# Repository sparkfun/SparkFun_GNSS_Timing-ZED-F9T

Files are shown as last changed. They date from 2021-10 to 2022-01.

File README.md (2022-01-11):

SparkFun GNSS Timing Breakout - ZED-F9T (Qwiic)
========================================

SparkFun GNSS Timing Breakout - ZED-F9T (Qwiic) (https://www.sparkfun.com/products/18774)

[*SparkFun GNSS Timing Breakout - ZED-F9T (Qwiic) (GPS-18774)*](https://www.sparkfun.com/products/18774)

The SparkFun GNSS Timing Breakout - ZED-F9T (Qwiic) offers a unique entry into SparkFun&apos;s GNSS catalog featuring the ZED-F9T GNSS receiver from u-blox. The ZED-F9T provides up to 5 nanosecond timing accuracy under clear skies with no external GNSS correction. The ZED-F9T supports L1/L2 bands and operates on all major constellations concurrently so it is able to maintain its timing precision even if the module loses connection with on or more of the visible constellations.

The breakout includes a USB-C connector for primary power and communication, two Qwiic connectors for communicating over I<sup>2</sup>C using the SparkFun [Qwiic system](https://www.sparkfun.com/qwiic), three SMA connectors for the antenna and timing pulse signals as well as a host of PTH pins allowing direct interaction with most of the ZED-F9T's pinout. The board also includes an on-board rechargeable battery that provides power to the RTC on the ZED-F9T. This reduces the time-to-first fix from a cold start (~24s) to a hot start (~2s). 

Repository Contents
-------------------

* **/Documents** - Datasheet, Appnotes.
* **/Hardware** - Eagle design files (.brd, .sch)

Documentation
-------------

* **[SparkFun u-blox GNSS Arduino Library](https://github.com/sparkfun/SparkFun_u-blox_GNSS_Arduino_Library)** - A comprehensive library for all SparkFun u-blox products.
* **[Hookup Guide](https://learn.sparkfun.com/tutorials/gnss-timing-breakout---zed-f9t-qwiic-hookup-guide)** - A basic Hookup Guide to get started with the SparkFun GNSS Timing Breakout - ZED-F9T (Qwiic).

Product Versions
----------------
* [GPS-18774](https://www.sparkfun.com/products/18774) - Initial release

Version History
---------------
* v1.0 - Initial Release 

License Information
-------------------

This product is _**open source**_! 

Please review the LICENSE.md file for license information. 

If you have any questions or concerns on licensing, please contact technical support on our [SparkFun forums](https://forum.sparkfun.com/viewforum.php?f=152).

Distributed as-is; no warranty is given.

- Your friends at SparkFun.

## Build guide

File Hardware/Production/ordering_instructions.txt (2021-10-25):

panel size, 199x101mm
PCB thickness, 1.6mm
number of layers, 4
controlled impedance, JLC7628
soldermask color, Red
silkscreen color, White
oz copper, 1oz
finish, ENIG
stencils, none
pcs per panel, 8
min trace width, 0.1778mm / 0.0070in
min drill size, 0.3048mm / 0.0120in
filename to layer stackup 1/2/3/4: GTL, GL2, GL3, GBL

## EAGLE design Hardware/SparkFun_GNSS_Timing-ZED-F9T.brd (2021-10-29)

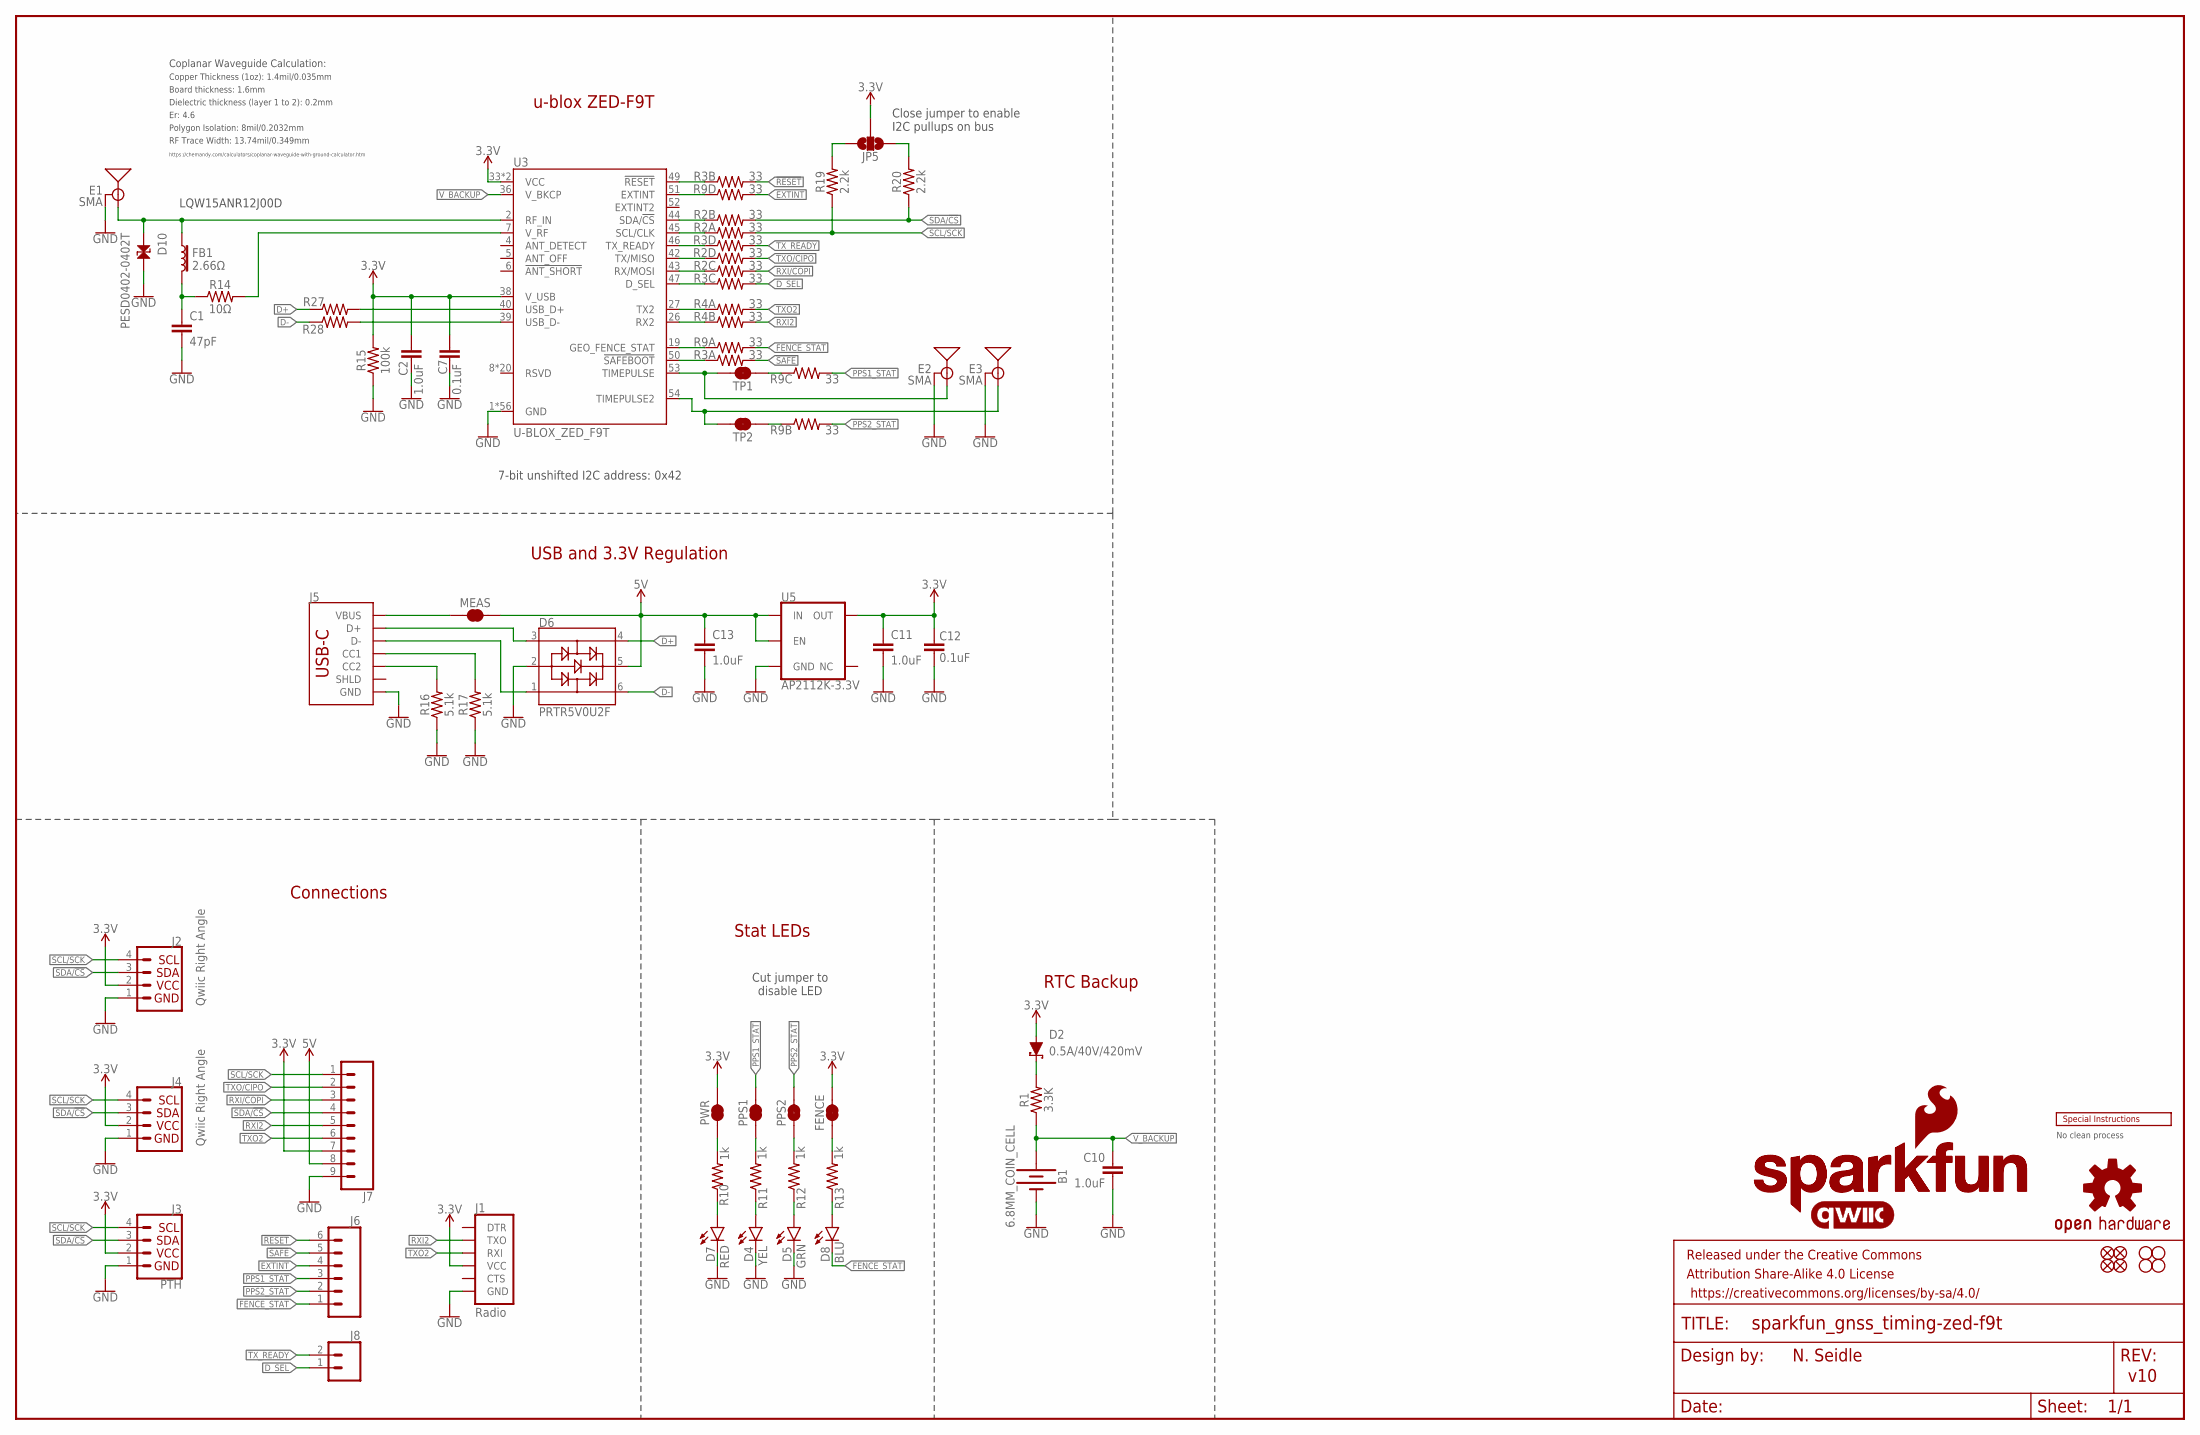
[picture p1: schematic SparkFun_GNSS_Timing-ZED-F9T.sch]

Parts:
B1: 6.8MM_COIN_CELL; ML414H_IV01E
C1: 47pF; 0402-TIGHT
C2, C10, C11, C13: 1.0uF; 0402-TIGHT
C7, C12: 0.1uF; 0402-TIGHT
D2: 0.5A/40V/420mV; SOD-323
D4: YEL; LED-0603
D5: GRN; LED-0603
D6: PRTR5V0U2F; SOT886
D7: RED; LED-0603
D8: BLU; LED-0603
D10: PESD0402-0402T; 0402-TIGHT
E1, E2, E3: SMA; SMA-EDGE
FB1: 2.66Ω; 0402-TIGHT
FENCE: JUMPER-SMT_2_NC_TRACE_SILK; SMT-JUMPER_2_NC_TRACE_SILK
FRAME2: FRAME-LEDGER; CREATIVE_COMMONS
H1, H2, H3, H4: STAND-OFF
J1: Radio; 1X06_NO_SILK
J2, J4: Qwiic Right Angle; JST04_1MM_RA
J3: PTH; 1X04_NO_SILK
J5: USB Female Type C Connector; USB-C-16P_4LAYER-PADS
J6: CONN_06NO_SILK_FEMALE_PTH; 1X06_NO_SILK
J7: CONN_09NO_SILK; 1X09_NO_SILK
J8: CONN_021X02_NO_SILK; 1X02_NO_SILK
JP5: JUMPER-SMT_3_NO_SILK; SMT-JUMPER_3_NO_SILK
JP21, JP61, JP71, JP81: FIDUCIALUFIDUCIAL; FIDUCIAL-MICRO
LOGO1: OSHW-LOGOMINI; OSHW-LOGO-MINI
LOGO2: SFE_LOGO_NAME_FLAME.1_INCH; SFE_LOGO_NAME_FLAME_.1
LOGO4: QWIIC_LOGO_4MM; QWIIC_4MM
LOGO5: SFE_LOGO_NAME.1_INCH; SFE_LOGO_NAME_.1
MEAS: JUMPER-COMBO_2_NC_TRACE; COMBO-JUMPER_2_NC_TRACE
PPS1, PPS2: JUMPER-SMT_2_NC_TRACE_SILK; SMT-JUMPER_2_NC_TRACE_SILK
PWR: JUMPER-SMT_2_NC_TRACE_SILK; SMT-JUMPER_2_NC_TRACE_SILK
R1: 3.3K; 0402-TIGHT
R2, R3, R4, R9: 33; 1206_RA
R10, R11, R12, R13: 1k; 0402-TIGHT
R14: 10Ω; 0402-TIGHT
R15: 100k; 0402-TIGHT
R16, R17: 5.1k; 0402-TIGHT
R19, R20: 2.2k; 0402-TIGHT
R27, R28: 27OHM; 0402-TIGHT
TP1, TP2: JUMPER-SMT_2_NC_TRACE_SILK; SMT-JUMPER_2_NC_TRACE_SILK
U3: U-BLOX_ZED_F9T; ZED-F9X
U5: AP2112K-3.3V; SOT23-5
U$2: SPECIAL_INSTRUCTIONS-ORDERING; ORDERING_INSTRUCTIONS

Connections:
3.3V: C2.1, C7.2, C11.1, C12.2, D2.A, FENCE.2, J1.4 (VCC), J2.2, J3.2 (VCC), J4.2, J7.7, JP5.2, PWR.2, R15.2, U3.33 (VCC), U3.34 (VCC), U3.38 (V_USB), U5.5 (OUT)
5V: C13.1, D6.5, J7.8, MEAS.2, MEAS.4 (2), U5.1 (IN), U5.3 (EN)
!RESET!: J6.6, R3.P7 (2)
!RESET!_LV: R3.P2 (1), U3.49 (!RESET!)
!SAFE!: J6.5, R3.P8 (2)
!SAFE!_LV: R3.P1 (1), U3.50 (!SAFEBOOT!)
ANT_VCC: C1.1, FB1.2, R14.1
CC1: J5.A5 (CC1), R17.2
CC2: J5.B5 (CC2), R16.2
D+: D6.4, R27.1
D-: D6.6, R28.1
DSEL_LV: R3.P3 (1), U3.47 (D_SEL)
D_SEL: J8.1, R3.P6 (2)
EXTINT: J6.4, R9.P5 (2)
EXTINT_LV: R9.P4 (1), U3.51 (EXTINT)
FENCE_LV: R9.P1 (1), U3.19 (GEO_FENCE_STAT)
FENCE_STAT: D8.C, J6.1, R9.P8 (2)
GND: B1.-, C1.2, C2.2, C7.1, C10.2, C11.2, C12.1, C13.2, D4.C, D5.C, D6.2, D7.C, D10.2, E1.GND@0 (GND), E1.GND@1 (GND), E1.GND@2 (GND), E1.GND@3 (GND), E2.GND@0 (GND), E2.GND@1 (GND), E2.GND@2 (GND), E2.GND@3 (GND), E3.GND@0 (GND), E3.GND@1 (GND), E3.GND@2 (GND), E3.GND@3 (GND), J1.6 (GND), J2.1, J3.1 (GND), J4.1, J5.GND, J5.GND2 (GND), J7.9, R15.1, R16.1, R17.1, U3.1 (GND), U3.3 (GND), U3.12 (GND), U3.14 (GND), U3.32 (GND), U3.37 (GND), U3.41 (GND), U3.48 (GND), U3.G1 (GND), U3.G2 (GND), U3.G3 (GND), U3.G4 (GND), U3.G5 (GND), U3.G6 (GND), U3.G7 (GND), U3.G8 (GND), U3.G9 (GND), U3.G10 (GND), U3.G11 (GND), U3.G12 (GND), U3.G13 (GND), U3.G14 (GND), U3.G15 (GND), U3.G16 (GND), U3.G17 (GND), U3.G18 (GND), U3.G19 (GND), U3.G20 (GND), U3.G21 (GND), U3.G22 (GND), U3.G23 (GND), U3.G24 (GND), U3.G25 (GND), U3.G26 (GND), U3.G27 (GND), U3.G28 (GND), U3.G29 (GND), U3.G30 (GND), U3.G31 (GND), U3.G32 (GND), U3.G33 (GND), U3.G34 (GND), U3.G35 (GND), U3.G36 (GND), U3.G37 (GND), U3.G38 (GND), U3.G39 (GND), U3.G40 (GND), U3.G41 (GND), U3.G42 (GND), U3.G43 (GND), U3.G44 (GND), U3.G45 (GND), U3.G46 (GND), U3.G47 (GND), U3.G48 (GND), U5.2 (GND)
GPS_ANT1: D10.1, E1.SIG (SIGNAL), FB1.1, U3.2 (RF_IN)
unnamed: D4.A, R11.1
unnamed: PPS1.1, R11.2
unnamed: J5.VBUS1 (VBUS), J5.VBUS2 (VBUS), MEAS.1, MEAS.3 (1)
unnamed: R9.P3 (1), TP1.1
unnamed: D2.C, R1.2
unnamed: R9.P2 (1), TP2.1
unnamed: R27.2, U3.40 (USB_D+)
unnamed: R28.2, U3.39 (USB_D-)
unnamed: R14.2, U3.7 (V_RF)
unnamed: D7.A, R10.1
unnamed: D5.A, R12.1
unnamed: PPS2.1, R12.2
unnamed: D8.A, R13.1
unnamed: FENCE.1, R13.2
unnamed: PWR.1, R10.2
unnamed: JP5.1, R20.2
unnamed: JP5.3, R19.2
PPS1_STAT: J6.3, PPS1.2, R9.P6 (2)
PPS2_STAT: J6.2, PPS2.2, R9.P7 (2)
RX1_LV: R2.P3 (1), U3.43 (RX/MOSI)
RX2_LV: R4.P2 (1), U3.26 (RX2)
RXI2: J1.3 (TXO), J7.5, R4.P7 (2)
RXI/COPI: J7.3, R2.P6 (2)
SCL/SCK: J2.4, J3.4 (SCL), J4.4, J7.1, R2.P8 (2), R19.1
SCL_LV: R2.P1 (1), U3.45 (SCL/CLK)
SDA/!CS: J2.3, J3.3 (SDA), J4.3, J7.4, R2.P7 (2), R20.1
SDA_LV: R2.P2 (1), U3.44 (SDA/!CS!)
TP1_LV: E2.SIG (SIGNAL), TP1.2, U3.53 (TIMEPULSE)
TP2_LV: E3.SIG (SIGNAL), TP2.2, U3.54 (TIMEPULSE2)
TX1_LV: R2.P4 (1), U3.42 (TX/MISO)
TX2_LV: R4.P1 (1), U3.27 (TX2)
TXO2: J1.2 (RXI), J7.6, R4.P8 (2)
TXO/CIPO: J7.2, R2.P5 (2)
TX_READY: J8.2, R3.P5 (2)
TX_READY_LV: R3.P4 (1), U3.46 (TX_READY)
UNP_D+: D6.3, J5.A6 (D+), J5.B6 (D+)
UNP_D-: D6.1, J5.A7 (D-), J5.B7 (D-)
V_BACKUP: B1.+, C10.1, R1.1, U3.36 (V_BKCP)

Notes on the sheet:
v10
7-bit unshifted I2C address: 0x42
u-blox ZED-F9T
LQW15ANR12J00D
Board thickness: 1.6mm
Er: 4.6
Copper Thickness (1oz): 1.4mil/0.035mm
RF Trace Width: 13.74mil/0.349mm
Polygon Isolation: 8mil/0.2032mm
No clean process
Dielectric thickness (layer 1 to 2): 0.2mm
https://chemandy.com/calculators/coplanar-waveguide-with-ground-calculator.htm
Coplanar Waveguide Calculation:
USB and 3.3V Regulation
N. Seidle
Cut jumper to disable LED
RTC Backup
Close jumper to enable I2C pullups on bus
Stat LEDs
Connections

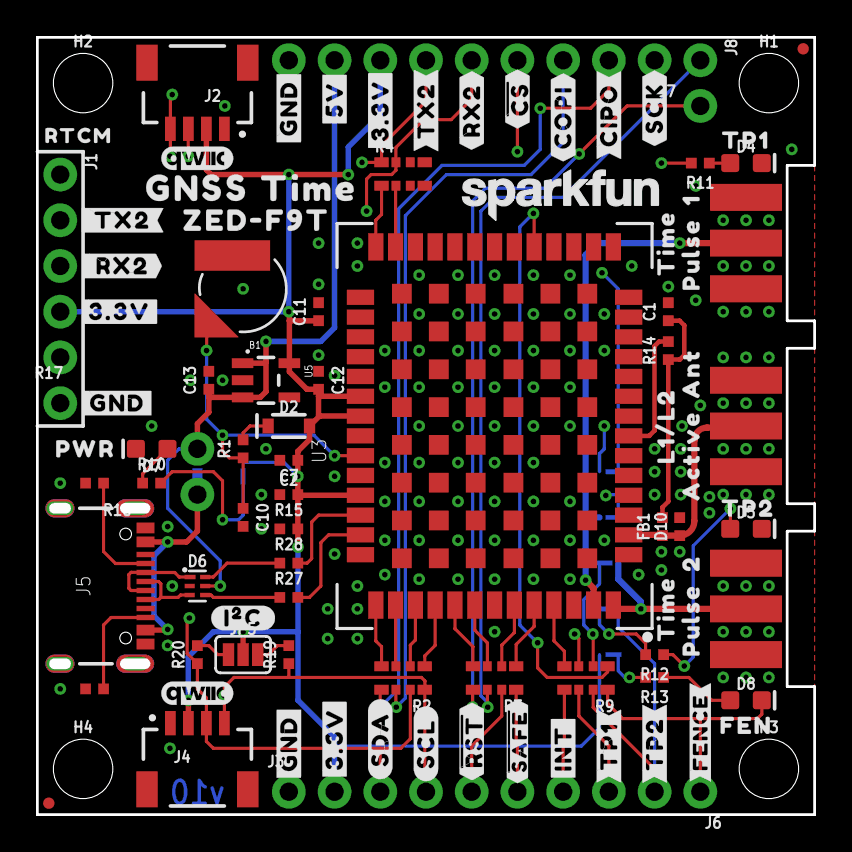
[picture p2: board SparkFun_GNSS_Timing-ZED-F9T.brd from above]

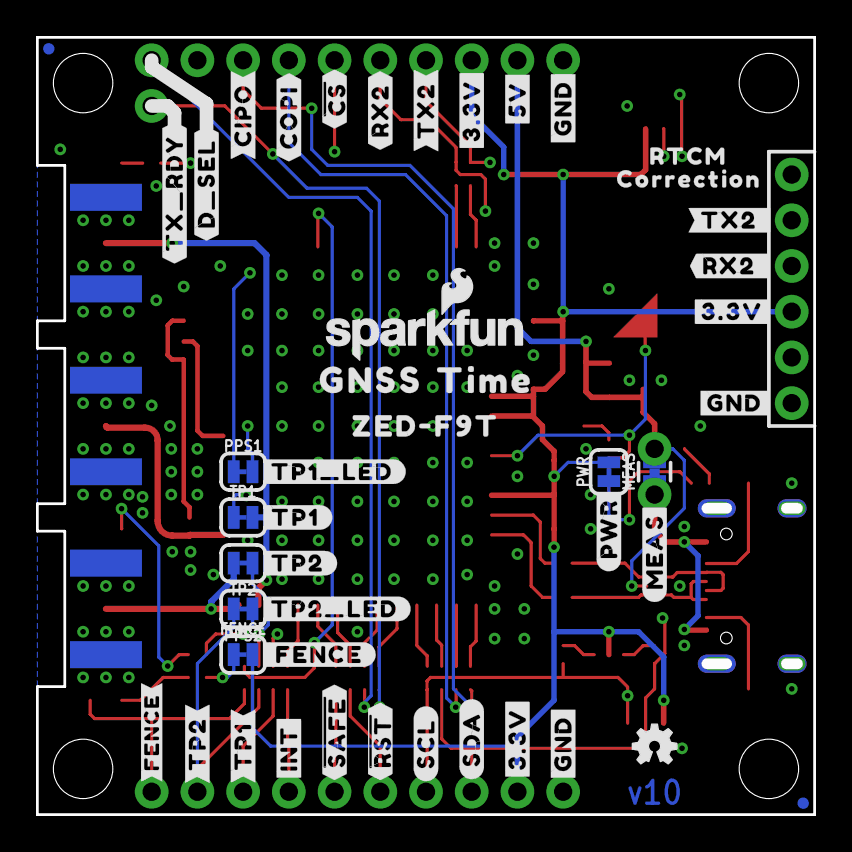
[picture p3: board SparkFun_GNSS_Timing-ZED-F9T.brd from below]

Board: 4 copper layers, 43.2 x 43.2 mm, 146 parts (47 on the bottom side), 57 nets.

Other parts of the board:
LOGO3: QWIIC_LOGO_4MM; QWIIC_4MM
U$1, U$29, U$35, U$36, U$59, U$60: #3#3V#0
U$3, U$28: #5V#1
U$4, U$27, U$38, U$39, U$61, U$62: #GND#2
U$5, U$8: ##CS##4
U$6: L1#L20
U$7, U$21: TIME0
U$9, U$10: #CIPO#6
U$11, U$12: #COPI#5
U$13: ACTIVE1
U$14, U$16: #RX2#1
U$15, U$37: ##RST##0
U$17, U$53: #SCL#3
U$18, U$22: #SDA#2
U$19, U$25: PULSE1
U$20: 12
U$23, U$24: #TX2#0
U$26: 20
U$30: #SCK#5
U$31: ANT1
U$32: #_TX2#0
U$33: #D_SEL#1
U$34, U$77: ZED#F9T0
U$40, U$70: GNSS0
U$41: ##SAFE##1
U$42, U$43: #INT#2
U$44, U$65: #FENCE#0
U$45: #TP2_LED#0
U$46, U$47: #TP1#3
U$48, U$49: #TP2#4
U$50: #TP2#0
U$51: #_FENCE#0
U$52: #TP1#0
U$54: #TP1_LED#0
U$55: #_RX2#0
U$56: PWR0
U$57: #PWR#0
U$58: #RX2_#0
U$63: TP10
U$64: TP21
U$66: #TX2_#0
U$67: #TX_RDY#0
U$68: #MEAS#0
U$69: #I�C#0
U$71, U$74: TIME1
U$72: ##SAFE##0
U$73: RTCM0
U$75: CORRECTION1
U$76: RTCM_0
U$78: FEN0

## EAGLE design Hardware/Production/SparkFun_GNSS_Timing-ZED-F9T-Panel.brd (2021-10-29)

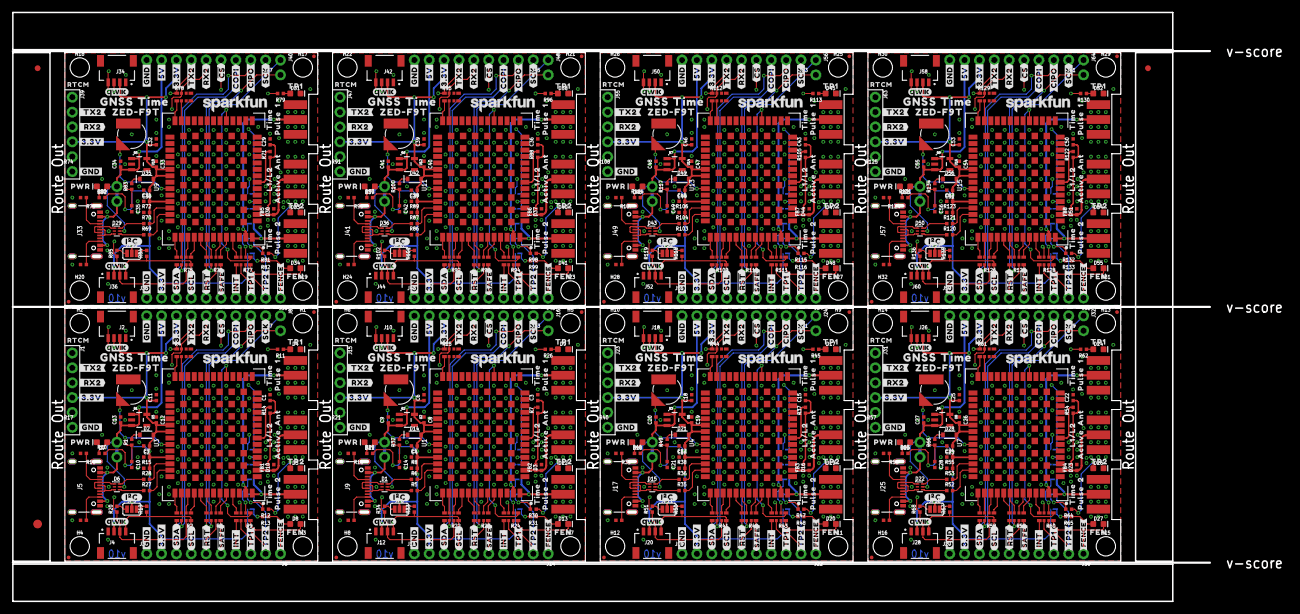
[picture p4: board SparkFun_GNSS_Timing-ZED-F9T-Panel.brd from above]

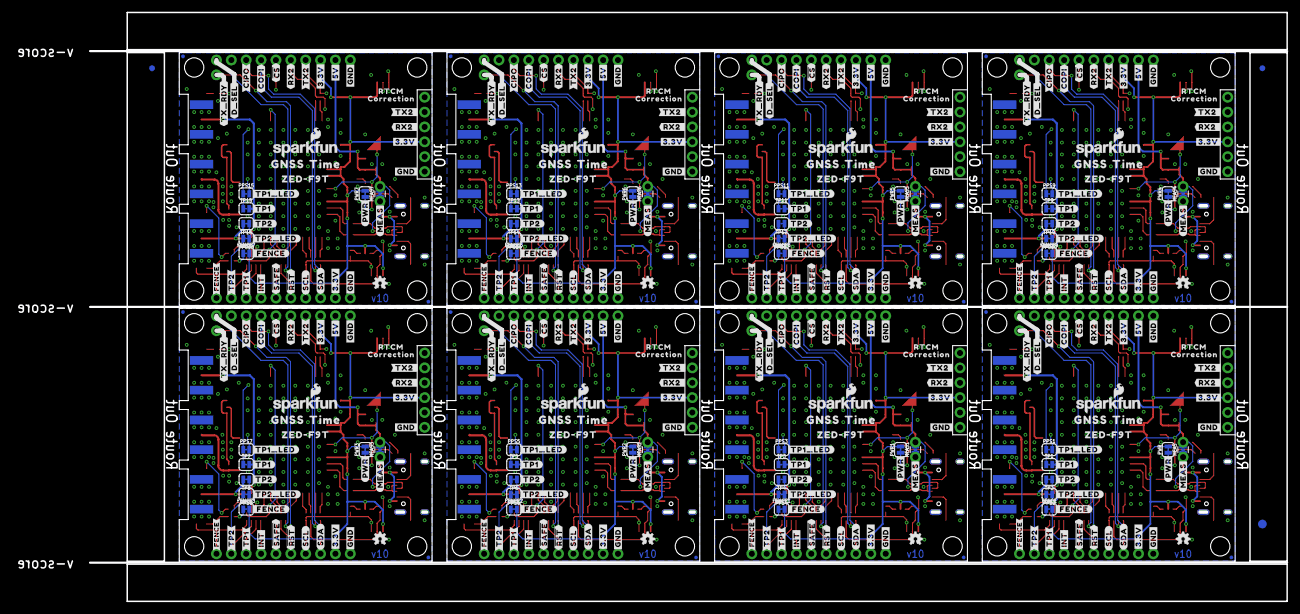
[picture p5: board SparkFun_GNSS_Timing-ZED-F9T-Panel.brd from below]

Board: 4 copper layers, 204.5 x 100.6 mm, 1158 parts (379 on the bottom side), 456 nets.

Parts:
B1, B2, B3, B4, B5, B6, B7, B8: 6.8MM_COIN_CELL; ML414H_IV01E
C1, C3, C15, C22, C29, C36, C43, C50: 47pF; 0402-TIGHT
C2, C4, C6, C9, C10, C11, C13, C14, C16, C18, C20, C21, C23, C25, C27, C28, C30, C32, C34, C35, C37, C39, C41, C42, C44, C46, C48, C49, C51, C53, C55, C56: 1.0uF; 0402-TIGHT
C5, C7, C8, C12, C17, C19, C24, C26, C31, C33, C38, C40, C45, C47, C52, C54: 0.1uF; 0402-TIGHT
D1, D6, D15, D22, D29, D36, D43, D50: PRTR5V0U2F; SOT886
D2, D14, D21, D28, D35, D42, D49, D56: 0.5A/40V/420mV; SOD-323
D3, D10, D16, D23, D30, D37, D44, D51: PESD0402-0402T; 0402-TIGHT
D4, D9, D17, D24, D31, D38, D45, D52: YEL; LED-0603
D5, D12, D19, D26, D33, D40, D47, D54: GRN; LED-0603
D7, D11, D18, D25, D32, D39, D46, D53: RED; LED-0603
D8, D13, D20, D27, D34, D41, D48, D55: BLU; LED-0603
E1, E2, E3, E4, E5, E6, E7, E8, E9, E10, E11, E12, E13, E14, E15, E16, E17, E18, E19, E20, E21, E22, E23, E24: SMA; SMA-EDGE
E$1, E$2, E$3, E$4: FIDUCIAL-1X2
E$5, E$6: FIDUCIAL-1.5X3
FB1, FB2, FB3, FB4, FB5, FB6, FB7, FB8: 2.66Ω; 0402-TIGHT
FENCE, FENCE1, FENCE2, FENCE3, FENCE4, FENCE5, FENCE6, FENCE7: JUMPER-SMT_2_NC_TRACE_SILK; SMT-JUMPER_2_NC_TRACE_SILK
H1, H2, H3, H4, H5, H6, H7, H8, H9, H10, H11, H12, H13, H14, H15, H16, H17, H18, H19, H20, H21, H22, H23, H24, H25, H26, H27, H28, H29, H30, H31, H32: STAND-OFF
J1, J15, J23, J31, J39, J47, J55, J63: Radio; 1X06_NO_SILK
J2, J4, J10, J12, J18, J20, J26, J28, J34, J36, J42, J44, J50, J52, J58, J60: Qwiic Right Angle; JST04_1MM_RA
J3, J11, J19, J27, J35, J43, J51, J59: PTH; 1X04_NO_SILK
J5, J9, J17, J25, J33, J41, J49, J57: USB Female Type C Connector; USB-C-16P_4LAYER-PADS
J6, J14, J22, J30, J38, J46, J54, J62: 1X06_NO_SILK
J7, J13, J21, J29, J37, J45, J53, J61: 1X09_NO_SILK
J8, J16, J24, J32, J40, J48, J56, J64: 1X02_NO_SILK
JP1, JP2, JP3, JP4, JP7, JP8, JP9, JP10, JP12, JP13, JP14, JP15, JP17, JP18, JP19, JP20, JP21, JP23, JP24, JP25, JP26, JP28, JP29, JP30, JP31, JP33, JP34, JP35, JP36, JP61, JP71, JP81: FIDUCIALUFIDUCIAL; FIDUCIAL-MICRO
JP5, JP6, JP11, JP16, JP22, JP27, JP32, JP37: JUMPER-SMT_3_NO_SILK; SMT-JUMPER_3_NO_SILK
LOGO1, LOGO6, LOGO11, LOGO16, LOGO21, LOGO26, LOGO31, LOGO36: OSHW-LOGOMINI; OSHW-LOGO-MINI
LOGO2, LOGO7, LOGO12, LOGO17, LOGO22, LOGO27, LOGO32, LOGO37: SFE_LOGO_NAME_FLAME.1_INCH; SFE_LOGO_NAME_FLAME_.1
LOGO3, LOGO4, LOGO8, LOGO10, LOGO13, LOGO15, LOGO18, LOGO20, LOGO23, LOGO25, LOGO28, LOGO30, LOGO33, LOGO35, LOGO38, LOGO40: QWIIC_LOGO_4MM; QWIIC_4MM
LOGO5, LOGO9, LOGO14, LOGO19, LOGO24, LOGO29, LOGO34, LOGO39: SFE_LOGO_NAME.1_INCH; SFE_LOGO_NAME_.1
MEAS, MEAS1, MEAS2, MEAS3, MEAS4, MEAS5, MEAS6, MEAS7: JUMPER-COMBO_2_NC_TRACE; COMBO-JUMPER_2_NC_TRACE
PPS1, PPS2, PPS3, PPS4, PPS5, PPS6, PPS7, PPS8, PPS9, PPS10, PPS11, PPS12, PPS13, PPS14, PPS15, PPS16: JUMPER-SMT_2_NC_TRACE_SILK; SMT-JUMPER_2_NC_TRACE_SILK
PWR, PWR1, PWR2, PWR3, PWR4, PWR5, PWR6, PWR7: JUMPER-SMT_2_NC_TRACE_SILK; SMT-JUMPER_2_NC_TRACE_SILK
R1, R32, R49, R66, R83, R100, R117, R134: 3.3K; 0402-TIGHT
R2, R3, R4, R9, R22, R23, R24, R25, R41, R42, R43, R44, R58, R59, R60, R61, R75, R76, R77, R78, R92, R93, R94, R95, R109, R110, R111, R112, R126, R127, R128, R129: 33; 1206_RA
R5, R6, R27, R28, R35, R36, R52, R53, R69, R70, R86, R87, R103, R104, R120, R121: 27OHM; 0402-TIGHT
R7, R14, R37, R54, R71, R88, R105, R122: 10Ω; 0402-TIGHT
R8, R15, R38, R55, R72, R89, R106, R123: 100k; 0402-TIGHT
R10, R11, R12, R13, R26, R29, R30, R31, R45, R46, R47, R48, R62, R63, R64, R65, R79, R80, R81, R82, R96, R97, R98, R99, R113, R114, R115, R116, R130, R131, R132, R133: 1k; 0402-TIGHT
R16, R17, R18, R21, R39, R40, R56, R57, R73, R74, R90, R91, R107, R108, R124, R125: 5.1k; 0402-TIGHT
R19, R20, R33, R34, R50, R51, R67, R68, R84, R85, R101, R102, R118, R119, R135, R136: 2.2k; 0402-TIGHT
TP1, TP2, TP3, TP4, TP5, TP6, TP7, TP8, TP9, TP10, TP11, TP12, TP13, TP14, TP15, TP16: JUMPER-SMT_2_NC_TRACE_SILK; SMT-JUMPER_2_NC_TRACE_SILK
U1, U3, U4, U7, U9, U11, U13, U15: U-BLOX_ZED_F9T; ZED-F9X
U2, U5, U6, U8, U10, U12, U14, U16: AP2112K-3.3V; SOT23-5
U$1, U$29, U$35, U$36, U$59, U$60, U$88, U$106, U$108, U$109, U$127, U$128, U$165, U$183, U$185, U$186, U$204, U$205, U$242, U$260, U$262, U$263, U$281, U$282, U$319, U$337, U$339, U$340, U$358, U$359, U$396, U$414, U$416, U$417, U$435, U$436, U$473, U$491, U$493, U$494, U$512, U$513, U$550, U$568, U$570, U$571, U$589, U$590: #3#3V#0
U$2, U$6, U$155, U$232, U$309, U$386, U$463, U$540: L1#L20
U$3, U$28, U$89, U$105, U$166, U$182, U$243, U$259, U$320, U$336, U$397, U$413, U$474, U$490, U$551, U$567: #5V#1
U$4, U$27, U$38, U$39, U$61, U$62, U$90, U$104, U$110, U$111, U$129, U$130, U$167, U$181, U$187, U$188, U$206, U$207, U$244, U$258, U$264, U$265, U$283, U$284, U$321, U$335, U$341, U$342, U$360, U$361, U$398, U$412, U$418, U$419, U$437, U$438, U$475, U$489, U$495, U$496, U$514, U$515, U$552, U$566, U$572, U$573, U$591, U$592: #GND#2
U$5, U$8, U$91, U$92, U$168, U$169, U$245, U$246, U$322, U$323, U$399, U$400, U$476, U$477, U$553, U$554: ##CS##4
U$7, U$21, U$80, U$83, U$157, U$160, U$234, U$237, U$311, U$314, U$388, U$391, U$465, U$468, U$542, U$545: TIME0
U$9, U$10, U$93, U$94, U$170, U$171, U$247, U$248, U$324, U$325, U$401, U$402, U$478, U$479, U$555, U$556: #CIPO#6
U$11, U$12, U$95, U$96, U$172, U$173, U$249, U$250, U$326, U$327, U$403, U$404, U$480, U$481, U$557, U$558: #COPI#5
U$13, U$79, U$156, U$233, U$310, U$387, U$464, U$541: ACTIVE1
U$14, U$16, U$97, U$98, U$174, U$175, U$251, U$252, U$328, U$329, U$405, U$406, U$482, U$483, U$559, U$560: #RX2#1
U$15, U$37, U$112, U$113, U$189, U$190, U$266, U$267, U$343, U$344, U$420, U$421, U$497, U$498, U$574, U$575: ##RST##0
U$17, U$53, U$87, U$99, U$164, U$176, U$241, U$253, U$318, U$330, U$395, U$407, U$472, U$484, U$549, U$561: #SCL#3
U$18, U$22, U$100, U$101, U$177, U$178, U$254, U$255, U$331, U$332, U$408, U$409, U$485, U$486, U$562, U$563: #SDA#2
U$19, U$25, U$81, U$84, U$158, U$161, U$235, U$238, U$312, U$315, U$389, U$392, U$466, U$469, U$543, U$546: PULSE1
U$20, U$82, U$159, U$236, U$313, U$390, U$467, U$544: 12
U$23, U$24, U$102, U$103, U$179, U$180, U$256, U$257, U$333, U$334, U$410, U$411, U$487, U$488, U$564, U$565: #TX2#0
U$26, U$85, U$162, U$239, U$316, U$393, U$470, U$547: 20
U$30, U$107, U$184, U$261, U$338, U$415, U$492, U$569: #SCK#5
U$31, U$86, U$163, U$240, U$317, U$394, U$471, U$548: ANT1
U$32, U$136, U$213, U$290, U$367, U$444, U$521, U$598: #_TX2#0
U$33, U$135, U$212, U$289, U$366, U$443, U$520, U$597: #D_SEL#1
U$34, U$77, U$146, U$153, U$223, U$230, U$300, U$307, U$377, U$384, U$454, U$461, U$531, U$538, U$608, U$615: ZED#F9T0
U$40, U$70, U$144, U$151, U$221, U$228, U$298, U$305, U$375, U$382, U$452, U$459, U$529, U$536, U$606, U$613: GNSS0
U$41, U$114, U$191, U$268, U$345, U$422, U$499, U$576: ##SAFE##1
U$42, U$43, U$115, U$116, U$192, U$193, U$269, U$270, U$346, U$347, U$423, U$424, U$500, U$501, U$577, U$578: #INT#2
U$44, U$65, U$121, U$133, U$198, U$210, U$275, U$287, U$352, U$364, U$429, U$441, U$506, U$518, U$583, U$595: #FENCE#0
U$45, U$126, U$203, U$280, U$357, U$434, U$511, U$588: #TP2_LED#0
U$46, U$47, U$117, U$118, U$194, U$195, U$271, U$272, U$348, U$349, U$425, U$426, U$502, U$503, U$579, U$580: #TP1#3
U$48, U$49, U$119, U$120, U$196, U$197, U$273, U$274, U$350, U$351, U$427, U$428, U$504, U$505, U$581, U$582: #TP2#4
U$50, U$123, U$200, U$277, U$354, U$431, U$508, U$585: #TP2#0
U$51, U$122, U$199, U$276, U$353, U$430, U$507, U$584: #_FENCE#0
U$52, U$124, U$201, U$278, U$355, U$432, U$509, U$586: #TP1#0
U$54, U$125, U$202, U$279, U$356, U$433, U$510, U$587: #TP1_LED#0
U$55, U$139, U$216, U$293, U$370, U$447, U$524, U$601: #_RX2#0
U$56, U$137, U$214, U$291, U$368, U$445, U$522, U$599: PWR0
U$57, U$138, U$215, U$292, U$369, U$446, U$523, U$600: #PWR#0
U$58, U$140, U$217, U$294, U$371, U$448, U$525, U$602: #RX2_#0
U$63, U$131, U$208, U$285, U$362, U$439, U$516, U$593: TP10
U$64, U$132, U$209, U$286, U$363, U$440, U$517, U$594: TP21
U$66, U$141, U$218, U$295, U$372, U$449, U$526, U$603: #TX2_#0
U$67, U$134, U$211, U$288, U$365, U$442, U$519, U$596: #TX_RDY#0
U$68, U$142, U$219, U$296, U$373, U$450, U$527, U$604: #MEAS#0
U$69, U$143, U$220, U$297, U$374, U$451, U$528, U$605: #I�C#0
U$71, U$74, U$145, U$152, U$222, U$229, U$299, U$306, U$376, U$383, U$453, U$460, U$530, U$537, U$607, U$614: TIME1
U$72, U$147, U$224, U$301, U$378, U$455, U$532, U$609: ##SAFE##0
U$73, U$148, U$225, U$302, U$379, U$456, U$533, U$610: RTCM0
U$75, U$149, U$226, U$303, U$380, U$457, U$534, U$611: CORRECTION1
U$76, U$150, U$227, U$304, U$381, U$458, U$535, U$612: RTCM_0
U$78, U$154, U$231, U$308, U$385, U$462, U$539, U$616: FEN0

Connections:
3.3V: C2.1, C7.2, C11.1, C12.2, D2.A, FENCE.2, J1.4, J2.2, J3.2, J4.2, J7.7, JP5.2, PWR.2, R15.2, U3.33, U3.34, U3.38, U5.5
3.3V1: C4.1, C5.2, C6.1, C8.2, D14.A, FENCE1.2, J10.2, J11.2, J12.2, J13.7, J15.4, JP6.2, PWR1.2, R8.2, U1.33, U1.34, U1.38, U2.5
3.3V2: C16.1, C17.2, C18.1, C19.2, D21.A, FENCE2.2, J18.2, J19.2, J20.2, J21.7, J23.4, JP11.2, PWR2.2, R38.2, U4.33, U4.34, U4.38, U6.5
3.3V3: C23.1, C24.2, C25.1, C26.2, D28.A, FENCE3.2, J26.2, J27.2, J28.2, J29.7, J31.4, JP16.2, PWR3.2, R55.2, U7.33, U7.34, U7.38, U8.5
3.3V4: C30.1, C31.2, C32.1, C33.2, D35.A, FENCE4.2, J34.2, J35.2, J36.2, J37.7, J39.4, JP22.2, PWR4.2, R72.2, U9.33, U9.34, U9.38, U10.5
3.3V5: C37.1, C38.2, C39.1, C40.2, D42.A, FENCE5.2, J42.2, J43.2, J44.2, J45.7, J47.4, JP27.2, PWR5.2, R89.2, U11.33, U11.34, U11.38, U12.5
3.3V6: C44.1, C45.2, C46.1, C47.2, D49.A, FENCE6.2, J50.2, J51.2, J52.2, J53.7, J55.4, JP32.2, PWR6.2, R106.2, U13.33, U13.34, U13.38, U14.5
3.3V7: C51.1, C52.2, C53.1, C54.2, D56.A, FENCE7.2, J58.2, J59.2, J60.2, J61.7, J63.4, JP37.2, PWR7.2, R123.2, U15.33, U15.34, U15.38, U16.5
5V: C13.1, D6.5, J7.8, MEAS.2, MEAS.4, U5.1, U5.3
5V1: C9.1, D1.5, J13.8, MEAS1.2, MEAS1.4, U2.1, U2.3
5V2: C20.1, D15.5, J21.8, MEAS2.2, MEAS2.4, U6.1, U6.3
5V3: C27.1, D22.5, J29.8, MEAS3.2, MEAS3.4, U8.1, U8.3
5V4: C34.1, D29.5, J37.8, MEAS4.2, MEAS4.4, U10.1, U10.3
5V5: C41.1, D36.5, J45.8, MEAS5.2, MEAS5.4, U12.1, U12.3
5V6: C48.1, D43.5, J53.8, MEAS6.2, MEAS6.4, U14.1, U14.3
5V7: C55.1, D50.5, J61.8, MEAS7.2, MEAS7.4, U16.1, U16.3
!RESET!: J6.6, R3.P7
!RESET!1: J14.6, R23.P7
!RESET!2: J22.6, R42.P7
!RESET!3: J30.6, R59.P7
!RESET!4: J38.6, R76.P7
!RESET!5: J46.6, R93.P7
!RESET!6: J54.6, R110.P7
!RESET!7: J62.6, R127.P7
!RESET!_LV: R3.P2, U3.49
!RESET!_LV1: R23.P2, U1.49
!RESET!_LV2: R42.P2, U4.49
!RESET!_LV3: R59.P2, U7.49
!RESET!_LV4: R76.P2, U9.49
!RESET!_LV5: R93.P2, U11.49
!RESET!_LV6: R110.P2, U13.49
!RESET!_LV7: R127.P2, U15.49
!SAFE!: J6.5, R3.P8
!SAFE!1: J14.5, R23.P8
!SAFE!2: J22.5, R42.P8
!SAFE!3: J30.5, R59.P8
!SAFE!4: J38.5, R76.P8
!SAFE!5: J46.5, R93.P8
!SAFE!6: J54.5, R110.P8
!SAFE!7: J62.5, R127.P8
!SAFE!_LV: R3.P1, U3.50
!SAFE!_LV1: R23.P1, U1.50
!SAFE!_LV2: R42.P1, U4.50
!SAFE!_LV3: R59.P1, U7.50
!SAFE!_LV4: R76.P1, U9.50
!SAFE!_LV5: R93.P1, U11.50
!SAFE!_LV6: R110.P1, U13.50
!SAFE!_LV7: R127.P1, U15.50
ANT_VCC: C1.1, FB1.2, R14.1
ANT_VCC1: C3.1, FB2.2, R7.1
ANT_VCC2: C15.1, FB3.2, R37.1
ANT_VCC3: C22.1, FB4.2, R54.1
ANT_VCC4: C29.1, FB5.2, R71.1
ANT_VCC5: C36.1, FB6.2, R88.1
ANT_VCC6: C43.1, FB7.2, R105.1
ANT_VCC7: C50.1, FB8.2, R122.1
CC1: J5.A5, R17.2
CC2: J5.B5, R16.2
CC3: J9.A5, R21.2
CC4: J9.B5, R18.2
CC5: J17.A5, R40.2
CC6: J17.B5, R39.2
CC7: J25.A5, R57.2
CC8: J25.B5, R56.2
CC9: J33.A5, R74.2
CC10: J33.B5, R73.2
CC11: J41.A5, R91.2
CC12: J41.B5, R90.2
CC13: J49.A5, R108.2
CC14: J49.B5, R107.2
CC15: J57.A5, R125.2
CC16: J57.B5, R124.2
D+: D6.4, R27.1
D+1: D1.4, R5.1
D+2: D15.4, R35.1
D+3: D22.4, R52.1
D+4: D29.4, R69.1
D+5: D36.4, R86.1
D+6: D43.4, R103.1
D+7: D50.4, R120.1
D-: D6.6, R28.1
D-1: D1.6, R6.1
D-2: D15.6, R36.1
D-3: D22.6, R53.1
D-4: D29.6, R70.1
D-5: D36.6, R87.1
D-6: D43.6, R104.1
D-7: D50.6, R121.1
DSEL_LV: R3.P3, U3.47
DSEL_LV1: R23.P3, U1.47
DSEL_LV2: R42.P3, U4.47
DSEL_LV3: R59.P3, U7.47
DSEL_LV4: R76.P3, U9.47
DSEL_LV5: R93.P3, U11.47
DSEL_LV6: R110.P3, U13.47
DSEL_LV7: R127.P3, U15.47
D_SEL: J8.1, R3.P6
D_SEL1: J16.1, R23.P6
D_SEL2: J24.1, R42.P6
D_SEL3: J32.1, R59.P6
D_SEL4: J40.1, R76.P6
D_SEL5: J48.1, R93.P6
D_SEL6: J56.1, R110.P6
D_SEL7: J64.1, R127.P6
EXTINT: J6.4, R9.P5
EXTINT1: J14.4, R24.P5
EXTINT2: J22.4, R43.P5
EXTINT3: J30.4, R60.P5
EXTINT4: J38.4, R77.P5
EXTINT5: J46.4, R94.P5
EXTINT6: J54.4, R111.P5
EXTINT7: J62.4, R128.P5
EXTINT_LV: R9.P4, U3.51
EXTINT_LV1: R24.P4, U1.51
EXTINT_LV2: R43.P4, U4.51
EXTINT_LV3: R60.P4, U7.51
EXTINT_LV4: R77.P4, U9.51
EXTINT_LV5: R94.P4, U11.51
EXTINT_LV6: R111.P4, U13.51
EXTINT_LV7: R128.P4, U15.51
FENCE_LV: R9.P1, U3.19
FENCE_LV1: R24.P1, U1.19
FENCE_LV2: R43.P1, U4.19
FENCE_LV3: R60.P1, U7.19
FENCE_LV4: R77.P1, U9.19
FENCE_LV5: R94.P1, U11.19
FENCE_LV6: R111.P1, U13.19
FENCE_LV7: R128.P1, U15.19
FENCE_STAT: D8.C, J6.1, R9.P8
FENCE_STAT1: D13.C, J14.1, R24.P8
FENCE_STAT2: D20.C, J22.1, R43.P8
FENCE_STAT3: D27.C, J30.1, R60.P8
FENCE_STAT4: D34.C, J38.1, R77.P8
FENCE_STAT5: D41.C, J46.1, R94.P8
FENCE_STAT6: D48.C, J54.1, R111.P8
FENCE_STAT7: D55.C, J62.1, R128.P8
GND: B1.-, C1.2, C2.2, C7.1, C10.2, C11.2, C12.1, C13.2, D4.C, D5.C, D6.2, D7.C, D10.2, E1.GND@0, E1.GND@1, E1.GND@2, E1.GND@3, E2.GND@0, E2.GND@1, E2.GND@2, E2.GND@3, E3.GND@0, E3.GND@1, E3.GND@2, E3.GND@3, J1.6, J2.1, J3.1, J4.1, J5.GND, J5.GND2, J7.9, R15.1, R16.1, R17.1, U3.1, U3.3, U3.12, U3.14, U3.32, U3.37, U3.41, U3.48, U3.G1, U3.G2, U3.G3, U3.G4, U3.G5, U3.G6, U3.G7, U3.G8, U3.G9, U3.G10, U3.G11, U3.G12, U3.G13, U3.G14, U3.G15, U3.G16, U3.G17, U3.G18, U3.G19, U3.G20, U3.G21, U3.G22, U3.G23, U3.G24, U3.G25, U3.G26, U3.G27, U3.G28, U3.G29, U3.G30, U3.G31, U3.G32, U3.G33, U3.G34, U3.G35, U3.G36, U3.G37, U3.G38, U3.G39, U3.G40, U3.G41, U3.G42, U3.G43, U3.G44, U3.G45, U3.G46, U3.G47, U3.G48, U5.2
GND1: B2.-, C3.2, C4.2, C5.1, C6.2, C8.1, C9.2, C14.2, D1.2, D3.2, D9.C, D11.C, D12.C, E4.GND@0, E4.GND@1, E4.GND@2, E4.GND@3, E5.GND@0, E5.GND@1, E5.GND@2, E5.GND@3, E6.GND@0, E6.GND@1, E6.GND@2, E6.GND@3, J9.GND, J9.GND2, J10.1, J11.1, J12.1, J13.9, J15.6, R8.1, R18.1, R21.1, U1.1, U1.3, U1.12, U1.14, U1.32, U1.37, U1.41, U1.48, U1.G1, U1.G2, U1.G3, U1.G4, U1.G5, U1.G6, U1.G7, U1.G8, U1.G9, U1.G10, U1.G11, U1.G12, U1.G13, U1.G14, U1.G15, U1.G16, U1.G17, U1.G18, U1.G19, U1.G20, U1.G21, U1.G22, U1.G23, U1.G24, U1.G25, U1.G26, U1.G27, U1.G28, U1.G29, U1.G30, U1.G31, U1.G32, U1.G33, U1.G34, U1.G35, U1.G36, U1.G37, U1.G38, U1.G39, U1.G40, U1.G41, U1.G42, U1.G43, U1.G44, U1.G45, U1.G46, U1.G47, U1.G48, U2.2
GND2: B3.-, C15.2, C16.2, C17.1, C18.2, C19.1, C20.2, C21.2, D15.2, D16.2, D17.C, D18.C, D19.C, E7.GND@0, E7.GND@1, E7.GND@2, E7.GND@3, E8.GND@0, E8.GND@1, E8.GND@2, E8.GND@3, E9.GND@0, E9.GND@1, E9.GND@2, E9.GND@3, J17.GND, J17.GND2, J18.1, J19.1, J20.1, J21.9, J23.6, R38.1, R39.1, R40.1, U4.1, U4.3, U4.12, U4.14, U4.32, U4.37, U4.41, U4.48, U4.G1, U4.G2, U4.G3, U4.G4, U4.G5, U4.G6, U4.G7, U4.G8, U4.G9, U4.G10, U4.G11, U4.G12, U4.G13, U4.G14, U4.G15, U4.G16, U4.G17, U4.G18, U4.G19, U4.G20, U4.G21, U4.G22, U4.G23, U4.G24, U4.G25, U4.G26, U4.G27, U4.G28, U4.G29, U4.G30, U4.G31, U4.G32, U4.G33, U4.G34, U4.G35, U4.G36, U4.G37, U4.G38, U4.G39, U4.G40, U4.G41, U4.G42, U4.G43, U4.G44, U4.G45, U4.G46, U4.G47, U4.G48, U6.2
GND3: B4.-, C22.2, C23.2, C24.1, C25.2, C26.1, C27.2, C28.2, D22.2, D23.2, D24.C, D25.C, D26.C, E10.GND@0, E10.GND@1, E10.GND@2, E10.GND@3, E11.GND@0, E11.GND@1, E11.GND@2, E11.GND@3, E12.GND@0, E12.GND@1, E12.GND@2, E12.GND@3, J25.GND, J25.GND2, J26.1, J27.1, J28.1, J29.9, J31.6, R55.1, R56.1, R57.1, U7.1, U7.3, U7.12, U7.14, U7.32, U7.37, U7.41, U7.48, U7.G1, U7.G2, U7.G3, U7.G4, U7.G5, U7.G6, U7.G7, U7.G8, U7.G9, U7.G10, U7.G11, U7.G12, U7.G13, U7.G14, U7.G15, U7.G16, U7.G17, U7.G18, U7.G19, U7.G20, U7.G21, U7.G22, U7.G23, U7.G24, U7.G25, U7.G26, U7.G27, U7.G28, U7.G29, U7.G30, U7.G31, U7.G32, U7.G33, U7.G34, U7.G35, U7.G36, U7.G37, U7.G38, U7.G39, U7.G40, U7.G41, U7.G42, U7.G43, U7.G44, U7.G45, U7.G46, U7.G47, U7.G48, U8.2
GND4: B5.-, C29.2, C30.2, C31.1, C32.2, C33.1, C34.2, C35.2, D29.2, D30.2, D31.C, D32.C, D33.C, E13.GND@0, E13.GND@1, E13.GND@2, E13.GND@3, E14.GND@0, E14.GND@1, E14.GND@2, E14.GND@3, E15.GND@0, E15.GND@1, E15.GND@2, E15.GND@3, J33.GND, J33.GND2, J34.1, J35.1, J36.1, J37.9, J39.6, R72.1, R73.1, R74.1, U9.1, U9.3, U9.12, U9.14, U9.32, U9.37, U9.41, U9.48, U9.G1, U9.G2, U9.G3, U9.G4, U9.G5, U9.G6, U9.G7, U9.G8, U9.G9, U9.G10, U9.G11, U9.G12, U9.G13, U9.G14, U9.G15, U9.G16, U9.G17, U9.G18, U9.G19, U9.G20, U9.G21, U9.G22, U9.G23, U9.G24, U9.G25, U9.G26, U9.G27, U9.G28, U9.G29, U9.G30, U9.G31, U9.G32, U9.G33, U9.G34, U9.G35, U9.G36, U9.G37, U9.G38, U9.G39, U9.G40, U9.G41, U9.G42, U9.G43, U9.G44, U9.G45, U9.G46, U9.G47, U9.G48, U10.2
GND5: B6.-, C36.2, C37.2, C38.1, C39.2, C40.1, C41.2, C42.2, D36.2, D37.2, D38.C, D39.C, D40.C, E16.GND@0, E16.GND@1, E16.GND@2, E16.GND@3, E17.GND@0, E17.GND@1, E17.GND@2, E17.GND@3, E18.GND@0, E18.GND@1, E18.GND@2, E18.GND@3, J41.GND, J41.GND2, J42.1, J43.1, J44.1, J45.9, J47.6, R89.1, R90.1, R91.1, U11.1, U11.3, U11.12, U11.14, U11.32, U11.37, U11.41, U11.48, U11.G1, U11.G2, U11.G3, U11.G4, U11.G5, U11.G6, U11.G7, U11.G8, U11.G9, U11.G10, U11.G11, U11.G12, U11.G13, U11.G14, U11.G15, U11.G16, U11.G17, U11.G18, U11.G19, U11.G20, U11.G21, U11.G22, U11.G23, U11.G24, U11.G25, U11.G26, U11.G27, U11.G28, U11.G29, U11.G30, U11.G31, U11.G32, U11.G33, U11.G34, U11.G35, U11.G36, U11.G37, U11.G38, U11.G39, U11.G40, U11.G41, U11.G42, U11.G43, U11.G44, U11.G45, U11.G46, U11.G47, U11.G48, U12.2
GND6: B7.-, C43.2, C44.2, C45.1, C46.2, C47.1, C48.2, C49.2, D43.2, D44.2, D45.C, D46.C, D47.C, E19.GND@0, E19.GND@1, E19.GND@2, E19.GND@3, E20.GND@0, E20.GND@1, E20.GND@2, E20.GND@3, E21.GND@0, E21.GND@1, E21.GND@2, E21.GND@3, J49.GND, J49.GND2, J50.1, J51.1, J52.1, J53.9, J55.6, R106.1, R107.1, R108.1, U13.1, U13.3, U13.12, U13.14, U13.32, U13.37, U13.41, U13.48, U13.G1, U13.G2, U13.G3, U13.G4, U13.G5, U13.G6, U13.G7, U13.G8, U13.G9, U13.G10, U13.G11, U13.G12, U13.G13, U13.G14, U13.G15, U13.G16, U13.G17, U13.G18, U13.G19, U13.G20, U13.G21, U13.G22, U13.G23, U13.G24, U13.G25, U13.G26, U13.G27, U13.G28, U13.G29, U13.G30, U13.G31, U13.G32, U13.G33, U13.G34, U13.G35, U13.G36, U13.G37, U13.G38, U13.G39, U13.G40, U13.G41, U13.G42, U13.G43, U13.G44, U13.G45, U13.G46, U13.G47, U13.G48, U14.2
GND7: B8.-, C50.2, C51.2, C52.1, C53.2, C54.1, C55.2, C56.2, D50.2, D51.2, D52.C, D53.C, D54.C, E22.GND@0, E22.GND@1, E22.GND@2, E22.GND@3, E23.GND@0, E23.GND@1, E23.GND@2, E23.GND@3, E24.GND@0, E24.GND@1, E24.GND@2, E24.GND@3, J57.GND, J57.GND2, J58.1, J59.1, J60.1, J61.9, J63.6, R123.1, R124.1, R125.1, U15.1, U15.3, U15.12, U15.14, U15.32, U15.37, U15.41, U15.48, U15.G1, U15.G2, U15.G3, U15.G4, U15.G5, U15.G6, U15.G7, U15.G8, U15.G9, U15.G10, U15.G11, U15.G12, U15.G13, U15.G14, U15.G15, U15.G16, U15.G17, U15.G18, U15.G19, U15.G20, U15.G21, U15.G22, U15.G23, U15.G24, U15.G25, U15.G26, U15.G27, U15.G28, U15.G29, U15.G30, U15.G31, U15.G32, U15.G33, U15.G34, U15.G35, U15.G36, U15.G37, U15.G38, U15.G39, U15.G40, U15.G41, U15.G42, U15.G43, U15.G44, U15.G45, U15.G46, U15.G47, U15.G48, U16.2
GPS_ANT1: D10.1, E1.SIG, FB1.1, U3.2
GPS_ANT2: D3.1, E4.SIG, FB2.1, U1.2
GPS_ANT3: D16.1, E7.SIG, FB3.1, U4.2
GPS_ANT4: D23.1, E10.SIG, FB4.1, U7.2
GPS_ANT5: D30.1, E13.SIG, FB5.1, U9.2
GPS_ANT6: D37.1, E16.SIG, FB6.1, U11.2
GPS_ANT7: D44.1, E19.SIG, FB7.1, U13.2
GPS_ANT8: D51.1, E22.SIG, FB8.1, U15.2
unnamed: R5.2, U1.40
unnamed: D4.A, R11.1
unnamed: PPS1.1, R11.2
unnamed: J5.VBUS1, J5.VBUS2, MEAS.1, MEAS.3
unnamed: R9.P3, TP1.1
unnamed: D2.C, R1.2
unnamed: R9.P2, TP2.1
unnamed: R6.2, U1.39
unnamed: R7.2, U1.7
unnamed: J9.VBUS1, J9.VBUS2, MEAS1.1, MEAS1.3
unnamed: R27.2, U3.40
unnamed: R28.2, U3.39
unnamed: R14.2, U3.7
unnamed: D7.A, R10.1
unnamed: D9.A, R26.1
unnamed: D5.A, R12.1
unnamed: PPS2.1, R12.2
unnamed: D8.A, R13.1
unnamed: FENCE.1, R13.2
unnamed: PWR.1, R10.2
unnamed: JP5.1, R20.2
unnamed: JP5.3, R19.2
unnamed: PPS3.1, R26.2
unnamed: D11.A, R29.1
unnamed: D12.A, R30.1
unnamed: PPS4.1, R30.2
unnamed: D13.A, R31.1
unnamed: FENCE1.1, R31.2
unnamed: PWR1.1, R29.2
unnamed: D14.C, R32.2
unnamed: JP6.1, R34.2
unnamed: JP6.3, R33.2
unnamed: R24.P3, TP3.1
unnamed: R24.P2, TP4.1
unnamed: R35.2, U4.40
unnamed: R36.2, U4.39
unnamed: R37.2, U4.7
unnamed: J17.VBUS1, J17.VBUS2, MEAS2.1, MEAS2.3
unnamed: D17.A, R45.1
unnamed: PPS5.1, R45.2
unnamed: D18.A, R46.1
unnamed: D19.A, R47.1
unnamed: PPS6.1, R47.2
unnamed: D20.A, R48.1
unnamed: FENCE2.1, R48.2
unnamed: PWR2.1, R46.2
unnamed: D21.C, R49.2
unnamed: JP11.1, R51.2
unnamed: JP11.3, R50.2
unnamed: R43.P3, TP5.1
unnamed: R43.P2, TP6.1
unnamed: R52.2, U7.40
unnamed: R53.2, U7.39
unnamed: R54.2, U7.7
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

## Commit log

2021-10-25 Add missing PROD IDs
    [SparkFun_GNSS_Timing-ZED-F9T.brd, SparkFun_GNSS_Timing-ZED-F9T.sch]
2021-10-27 Change RF trace width and other small changes from design review.
    [SparkFun_GNSS_Timing-ZED-F9T.brd, SparkFun_GNSS_Timing-ZED-F9T.sch]
2021-10-29 Add production panel.
    [SparkFun_GNSS_Timing-ZED-F9T-Panel.GBL, SparkFun_GNSS_Timing-ZED-F9T-Panel.GBO, SparkFun_GNSS_Timing-ZED-F9T-Panel.GBP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]

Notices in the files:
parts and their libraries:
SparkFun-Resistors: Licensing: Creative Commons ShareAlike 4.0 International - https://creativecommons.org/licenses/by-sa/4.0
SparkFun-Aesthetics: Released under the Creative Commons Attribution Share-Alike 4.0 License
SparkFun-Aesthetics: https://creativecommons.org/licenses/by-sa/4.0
